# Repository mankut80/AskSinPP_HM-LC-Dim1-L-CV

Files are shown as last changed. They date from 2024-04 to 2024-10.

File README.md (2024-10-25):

# HM-LC-DIM1L-CV

## 230V Dimmeraktor (Phasenanschnitt)

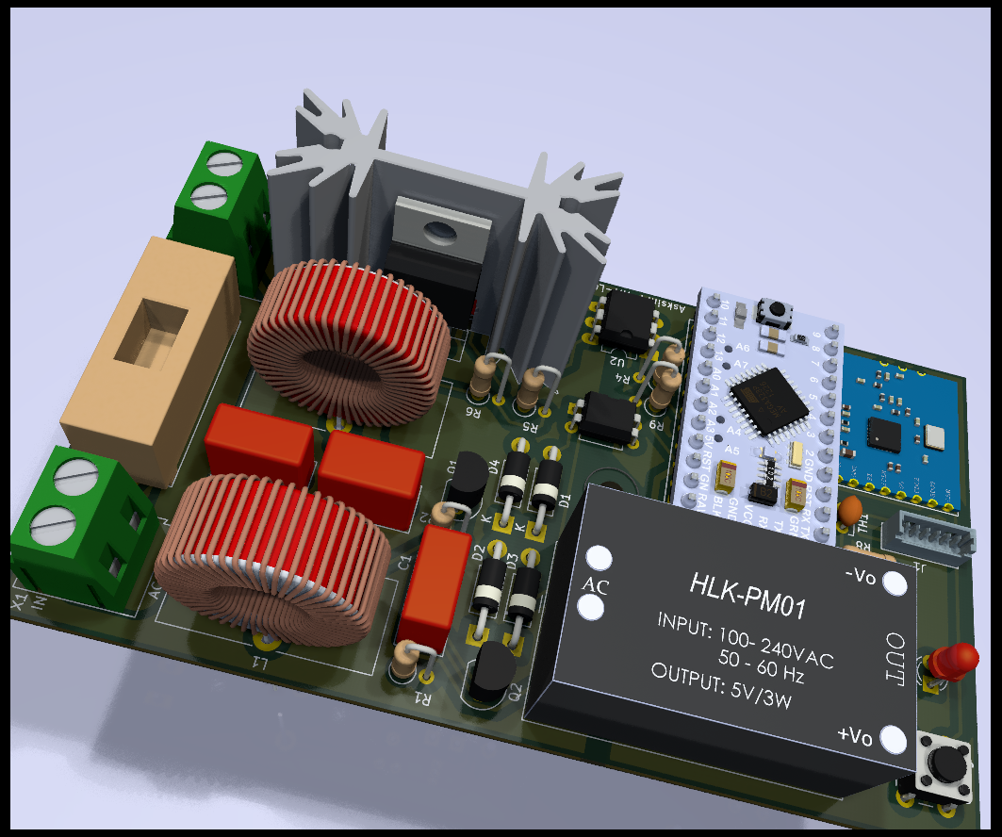
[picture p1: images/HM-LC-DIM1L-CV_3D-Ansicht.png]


*Hinweis zum Bild: das Netzteil HLK-PM01 im Bild ist in Wahrheit ein HLK-PM03 mit 3.3V Ausgangsspannung. Ich hatte leider kein passendes 3D-Modell gefunden.*

### Funktion

Mit der Technik des Phasenanschnitts lassen sich ohmsche und induktive Wechselstromlasten in der Leistung steuern. Da heutzutage wohl kaum noch jemand ein Interesse daran hat, Glühlampen zu dimmen, wird diese Schaltung eher für Motoren oder Transformatoren eingesetzt werden (Ventilatoren, Abluftmotoren). Über zwei Schraubklemmleisten wird sowohl die Netzspannung als auch der Verbraucher angeschlossen.

### Schaltungsbeschreibung

Siehe [PDF](pcb/HM-LC-DIM1L-CV_Schaltplan.pdf?fileId=26955)

Die benötigte Spannung von 3.3V wird vom PCB-Netzteil PS1 bereitgestellt und dient zur Versorgung des Arduino und des CC1101-Funkmoduls.

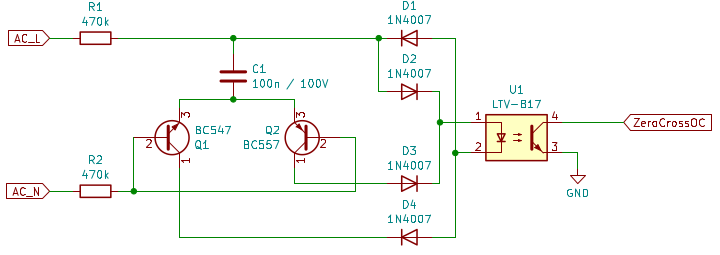
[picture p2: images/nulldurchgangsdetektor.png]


Ein diskret aufgebauter Nullspannungsdetektor liefert im Nulldurchgang der Netzspannung einen kurzen Impuls, welcher über den Optokoppler U1 an den Microcontroller gemeldet wird.

Der Leistungsteil besteht aus einem Optokoppler mit TRIAC-Ausgang welcher vom Arduino angesteuert wird, dem Leistungs-TRIAC und ein paar Filterbauteilen um Strom-/Spannungsspitzen zu dämpfen.  
Die Programmierung geschieht entweder wie üblich über den FTDI-Adapter direkt am Arduino oder über die ISP-Schnittstelle, herausgeführt an J1. J1 ist zugegeben nicht ganz die feine Art. Es ist ein in der Arduinowelt eher unüblicher Steckverbinder von Molex (Picoblade), den ich für private Zwecke gerne nutze. Er kann aber auch einfach weggelassen werden. Wer keine OTA-Updates braucht und somit nicht auf die Programmierung per ISP angewiesen ist, wird das nicht vermissen.

### Hinweise

Q1 und Q2, die beiden bipolaren Transistoren im Nulldurchgangsdetektor, können durch andere Standardtransistoren ersetzt werden. Sie müssen keine besonderen Merkmale aufweisen.  
Das Netzteil PS1 ist hoffnungslos überdimensionert, da würde auch eine Variante mit 200mA Ausgangstrom dicke ausreichen. Allerdings gab es diese Dinger nicht in einer kleineren Variante und auf ein Kondensator-"Netzteil" hatte ich keine Lust, da wäre das flashen mangels galvanischer Trennung zum Abenteuer geworden.

Der Haupt-TRIAC D6 kann auch durch andere Typen ersetzt werden. Die Wahl fiel von meiner Seite aus auf den BT138 weil mir dieser in Massen zur Verfügung steht ;-). Wer besonders kleine Leistungen schalten will, mag eventuell einen TRIAC mit kleinerem Haltestrom bevorzugen. Beim BT138 liegt dieser Haltestrom zwischen 4 und 30mA. In der Praxis bedeutet ein zu großer Haltestrom, dass die Last bei niedriger Leistungseinstellung zu flackern beginnt und eine ordentliche Steuerung erst ab höheren Steuergraden (>50%) möglich ist.

Der Heißleiter TH1 ist ebenfalls optional. Er dient zur Überwachung der Gehäuseinnentemperatur. Bei Bedarf kann man die Anschlüsse verlängern und ihn in der Nähe des Kühlkörpers platzieren. Oder ihn ganz weglassen (und im .ino-File auskommentieren).

#### Achtung 230V!

Bitte Vorsicht beim Nachbau. Wird der TRIAC ohne Isolierung am Kühlkörper angebracht, steht dieser unter Spannung, da fasst man leicht mal hin. Beim Anschluss des Verbrauchers darauf achten, dass dieser die Phase eventuell an einem bestimmten Anschluss haben will (z.B. bei einer Lampenfassung, da darf das Gewinde nicht auf die Phase gelegt werden). Rein von der Funktion her ist es egal, wo Phase und wo N angeschlossen wird.

### Bauteilliste

| Pos | Ref | Wert |
|-----|-----|---|
| 1 | C3, C4 | 47nF / 400V , RM 7.5, 10.3x7.5mm |
| 2 | C1, C2 | 100nF / 400V , RM 7.5, 10.3x7.5mm |
| 3 | R1, R2 | 470k, Bauform 0207, 1/4W |
| 4 | R3 | 330R, Bauform 0207, 1/4W |
| 5 | R4 | 150R, Bauform 0207, 1/4W |
| 6 | R5 | 360R, Baeeuform 0207, 1/4W |
| 7 | R6, R7 | 470R, Bauform 0207, 1/4W |
| 8 | R8 | 10k, Bauform 0207, 1/4W |
| 9 | R9 | 10k, Bauform 0207, 1/4W |
| 10 | L1, L2 | 100µH, 6A, Spule, z.B. Würth WUE 7447070 (bei Reichelt) |
| 11 | D1 - D4 | 1N4007 Gleichrichterdiode |
| 12 | D5 | LED, 3mm, Farbe egal |
| 13 | D6 | TRIAC BT138-600, TO220-Gehäuse |
| 14 | U1 | LTV-817 Optokoppler, DIP4 |
| 15 | U2 | MOC3052M Optokoppler mit TRIAC-Ausgang, DIP6 |
| 16 | U3 | CC1101-Funkmodul |
| 17 | X1, X2 | Schraubklemme 2pol., RM 5.08 oder RM5.00 |
| 18 | F1 | Sicherungshalter für Feinsicherungen 5x20mm und Sicherung 4A mittelträge |
| 19 | SW1 | Kurzhubtaster 6x6mm |
| 20 | A1 | Arduino Pro Mini 3.3V, 8MHz |
| 21 | PS1 | HLK-PM03 von HiLink, Netzteil 3.3V |
| 22 | Q1 | BC547, TO92, NPN-Transistor |
| 23 | Q2 | BC557, TO92, PNP-Transistor |
| 24 | TH1 | NTC 10k, Heißleiter, RM 2.5 |
| 25 | HS1 | Kühlkörper SK104 von Fischer |
| 26 | J1 | Molex Picoblade 53047-0610, Steckverbinder für ISP |

### Gehäuse

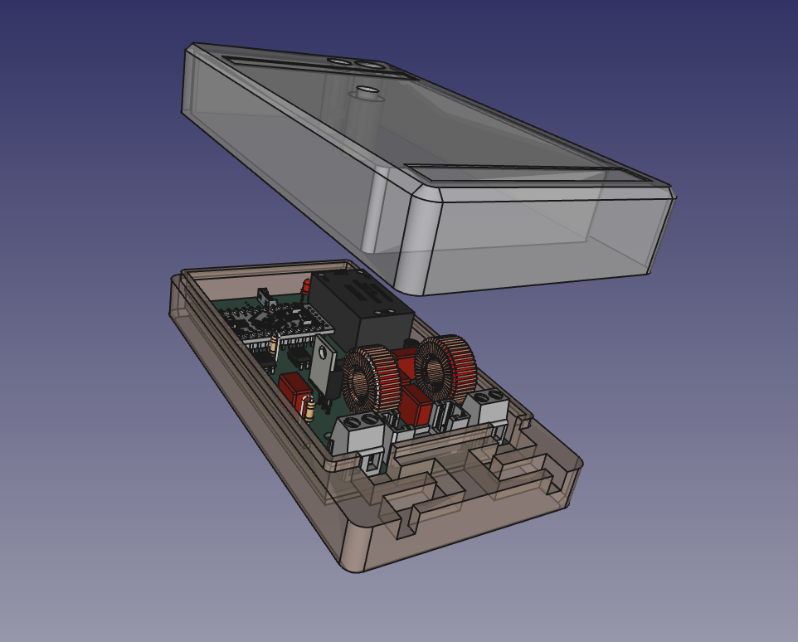
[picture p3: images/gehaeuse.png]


Das Gehäuse wurde in FreeCAD entworfen, die [Originaldatei](CAD/HM_AsksinPP_Phasenanschnitt_Gehaeuse.FCStd?fileId=26970) und zwei Step-Dateien ([Deckel](CAD/HM_AsksinPP_Phasenanschnitt_Gehaeuse-Oberteil.step?fileId=26968) und [Boden](CAD/HM_AsksinPP_Phasenanschnitt_Gehaeuse-Unterteil.step?fileId=26969)) zum Import in den Slicer (Prusaslicer frisst direkt step-Dateien) sind im CAD-Verzeichnis zu finden. Die lustigen, gezackten Vertiefungen für die Anschlussleitungen dienen als Zugentlastung. Im Deckel sind zwei kleine rechteckige Vertiefungen für Beschriftungsbänder, so man denn will.

Fertig aufgebaut sieht es dann so aus:

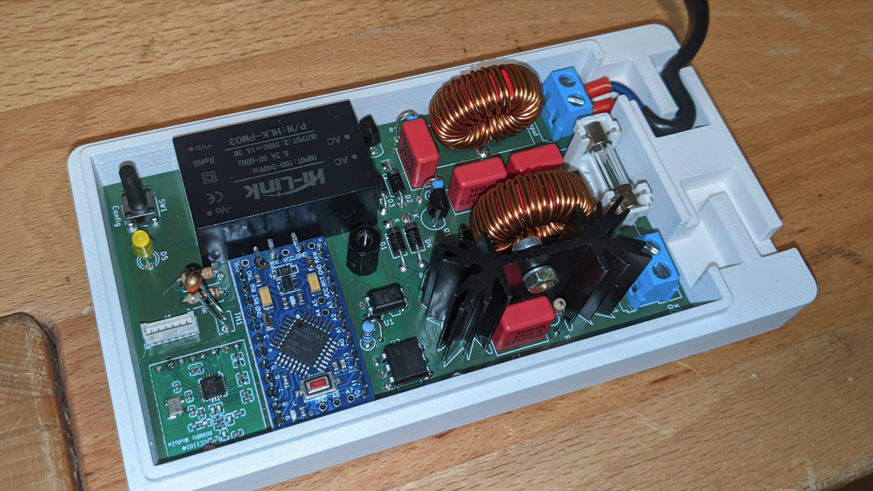
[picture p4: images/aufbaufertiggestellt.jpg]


Das Bild zeigt noch die Platine in der Revision A (aktuell ist C) mit einigen Fehlern, deshalb gleicht sie nicht 100%ig dem Bestückungsplan. Das CC1101-Modul hat als Antenne eine 83mm lange Litzenleitung bekommen, die sich im Gehäuse in einem kleinen Schlitz an der Seite verlegen lässt.

### Sketch

Als Sketch kommt eine abgeänderte Vorlage aus dem Asksin-Repo zum EInsatz. Die Serial muss natürlich geändert werden, außerdem ...

Ohne die  folgenden Änderungen wird nach dem EInschalten wiederholt (alle 40ms) kurz eingeschaltet, außerdem schaltet er nicht zuverlässig aus (geht manchmal auf Dauer-AN)

im main (\*.ino)-file, Funktion void setup():

```
phaseCut.stop();
```

innerhalb void loop():

```
if(!phaseCut.isrunning()) digitalWrite(DIMMERPIN, false);
```

Ohne die  folgenden Änderungen wird bei einer Dim-Einstellung von "0" auf Dauer-An gestellt:  
PhaseCut.cpp, Zeile 130:

```
if (_timer < 76 ) digitalWrite(OUTPUT_PIN, HIGH);
```
PhaseCut.cpp, Zeile 113, korrigieren des Setzens der Bits von Register TCCR2B (ist eher kosmetischer Natur):
```
TCCR2B |= (1 << CS20) | (1 << CS21) | (1 << CS22) ;
```

PWM.h, Zeile 25:

```
static const uint8_t zctable[50] PROGMEM = {
 9, 12, 13, 14, 15, 16, 17, 18, 19, 20, 21, 22, 23, 24, 25,26, 27, 28, 29, 30, 31, 32, 33, 34, 35, 36, 37, 38, 39, 40,41, 42, 43, 44, 45, 46, 47, 48, 49, 50, 53, 55, 60, 62, 64, 68, 70, 72, 76
};
```

PWM.h, Zeile 86:

```
#if PHASECUTMODE == 1    
  uint8_t offset = (STEPS - value)*49/STEPS;
```

Außerdem noch diese Änderung:
PhaseCut.h, Zeilen 10-16: 
Die Definitionen für PHASECUTMODE und ZEROPIN müssen abgeändert werden. Diese werden seltsamerweise nicht aus dem *.ino-File übernommen (vielen Dank an ivo-int für die Nachreichung dieser Information):

```
#ifndef PHASECUTMODE
#define PHASECUTMODE 1
#endif 

#ifndef ZEROPIN
#define ZEROPIN 3
#endif
```

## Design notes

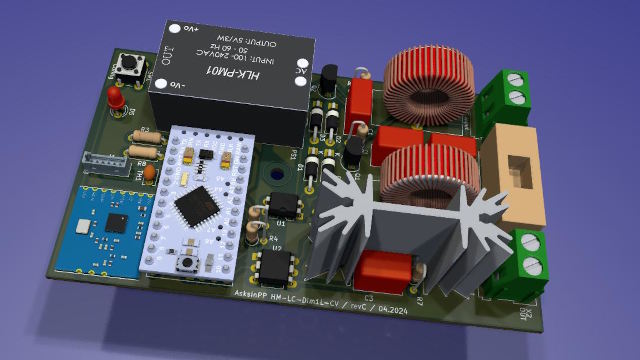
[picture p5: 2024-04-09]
images/thumb.jpg

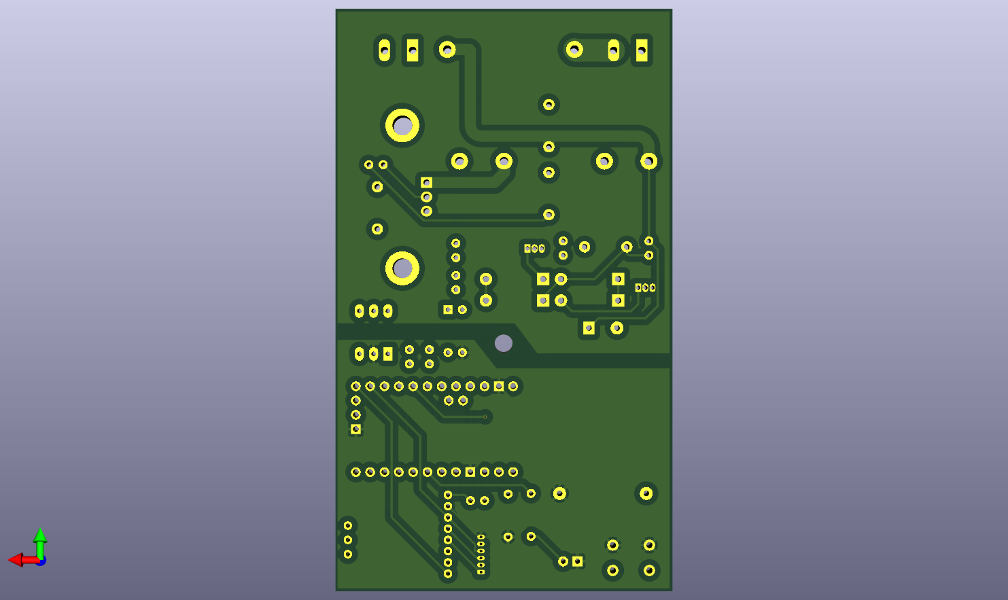
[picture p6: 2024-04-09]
pcb/HM-LC-DIM1L-CV_Board_Ansicht_unten.png

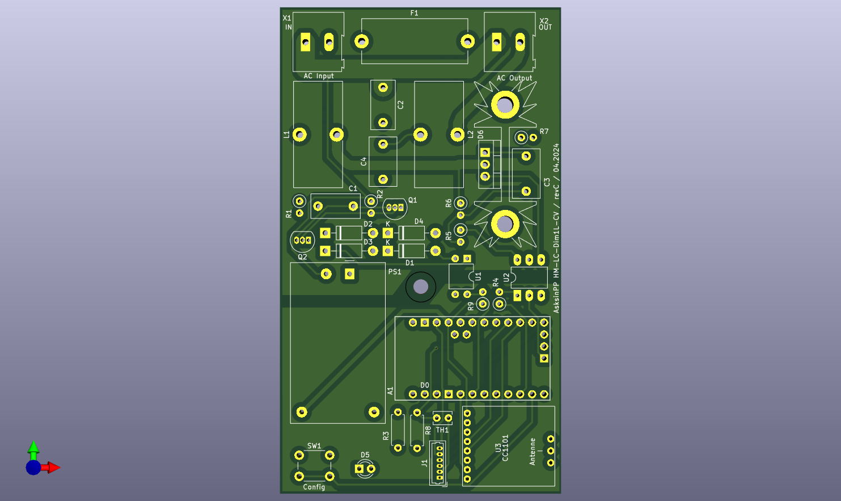
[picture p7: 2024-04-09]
pcb/HM-LC-DIM1L-CV_Board_Ansicht_oben.png

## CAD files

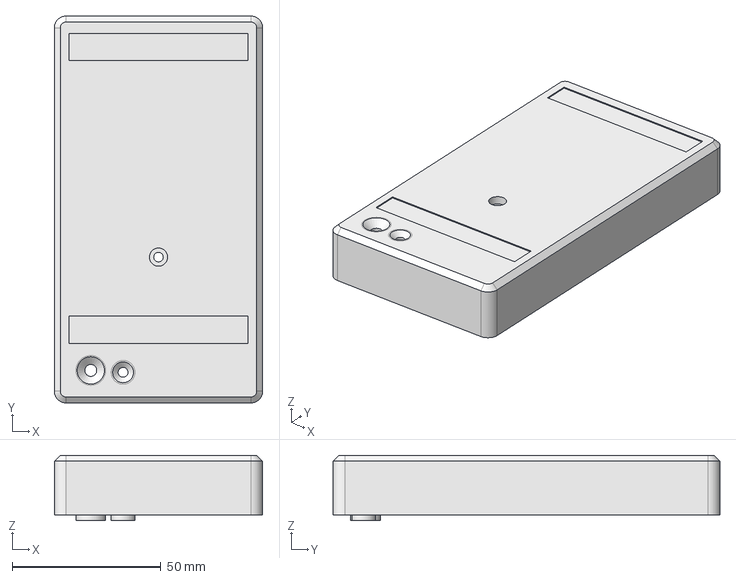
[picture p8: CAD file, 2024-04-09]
CAD/HM_AsksinPP_Phasenanschnitt_Gehaeuse-Oberteil.step
70.0 x 130.0 x 22.0 mm

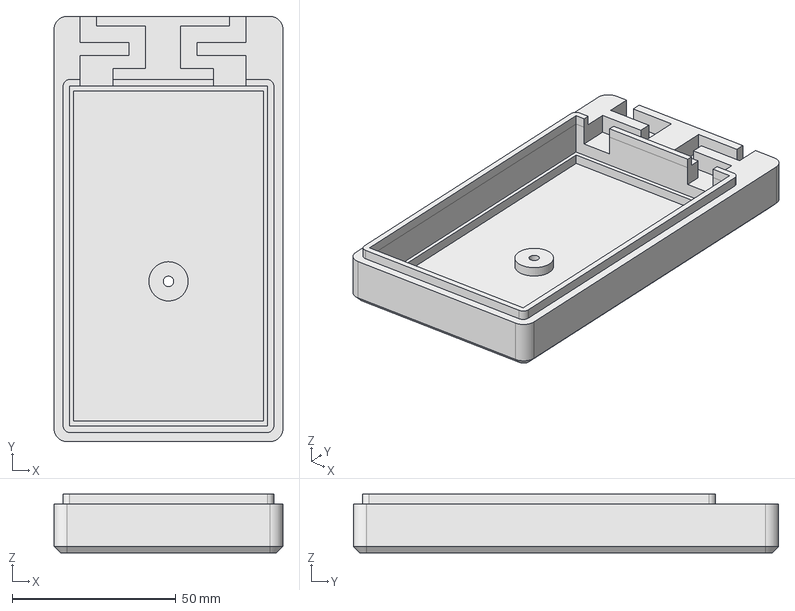
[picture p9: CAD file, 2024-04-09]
CAD/HM_AsksinPP_Phasenanschnitt_Gehaeuse-Unterteil.step
70.0 x 130.0 x 18.0 mm

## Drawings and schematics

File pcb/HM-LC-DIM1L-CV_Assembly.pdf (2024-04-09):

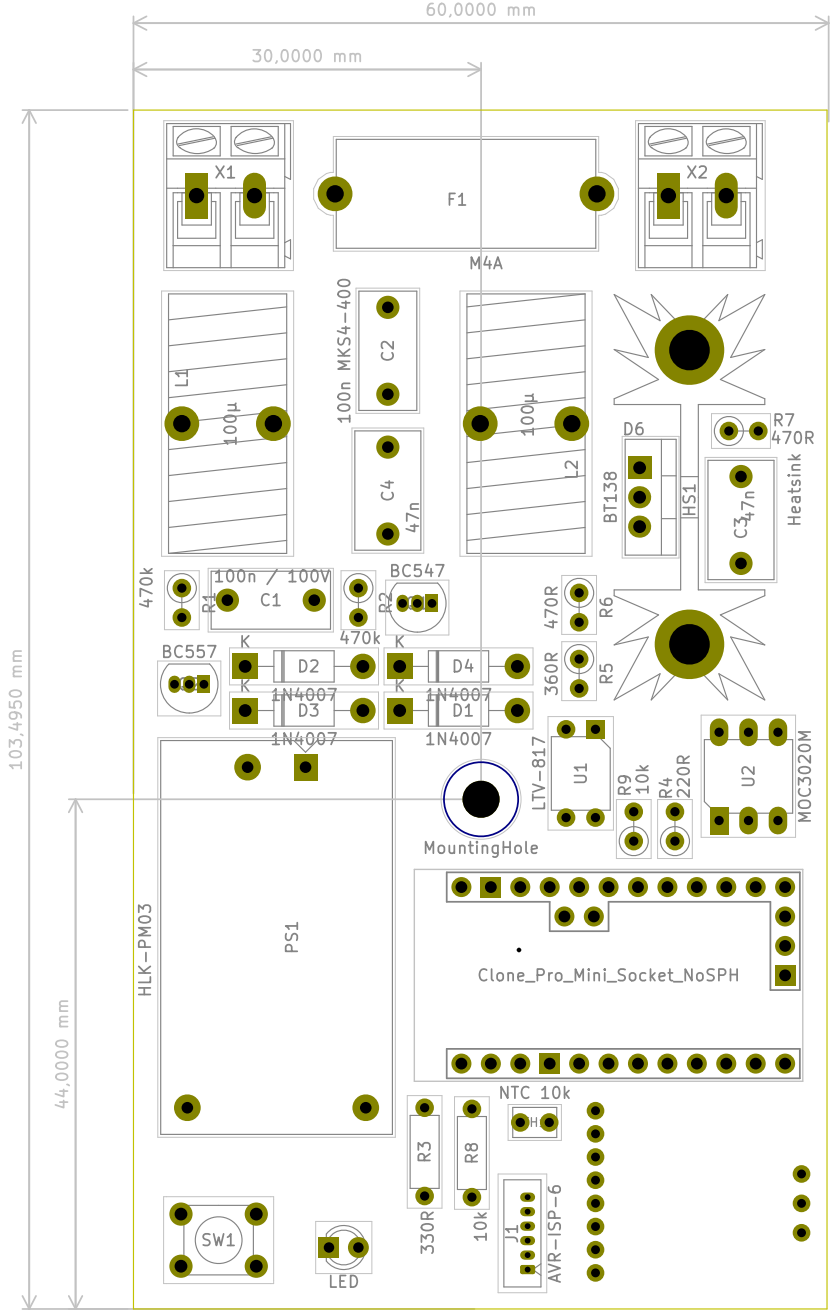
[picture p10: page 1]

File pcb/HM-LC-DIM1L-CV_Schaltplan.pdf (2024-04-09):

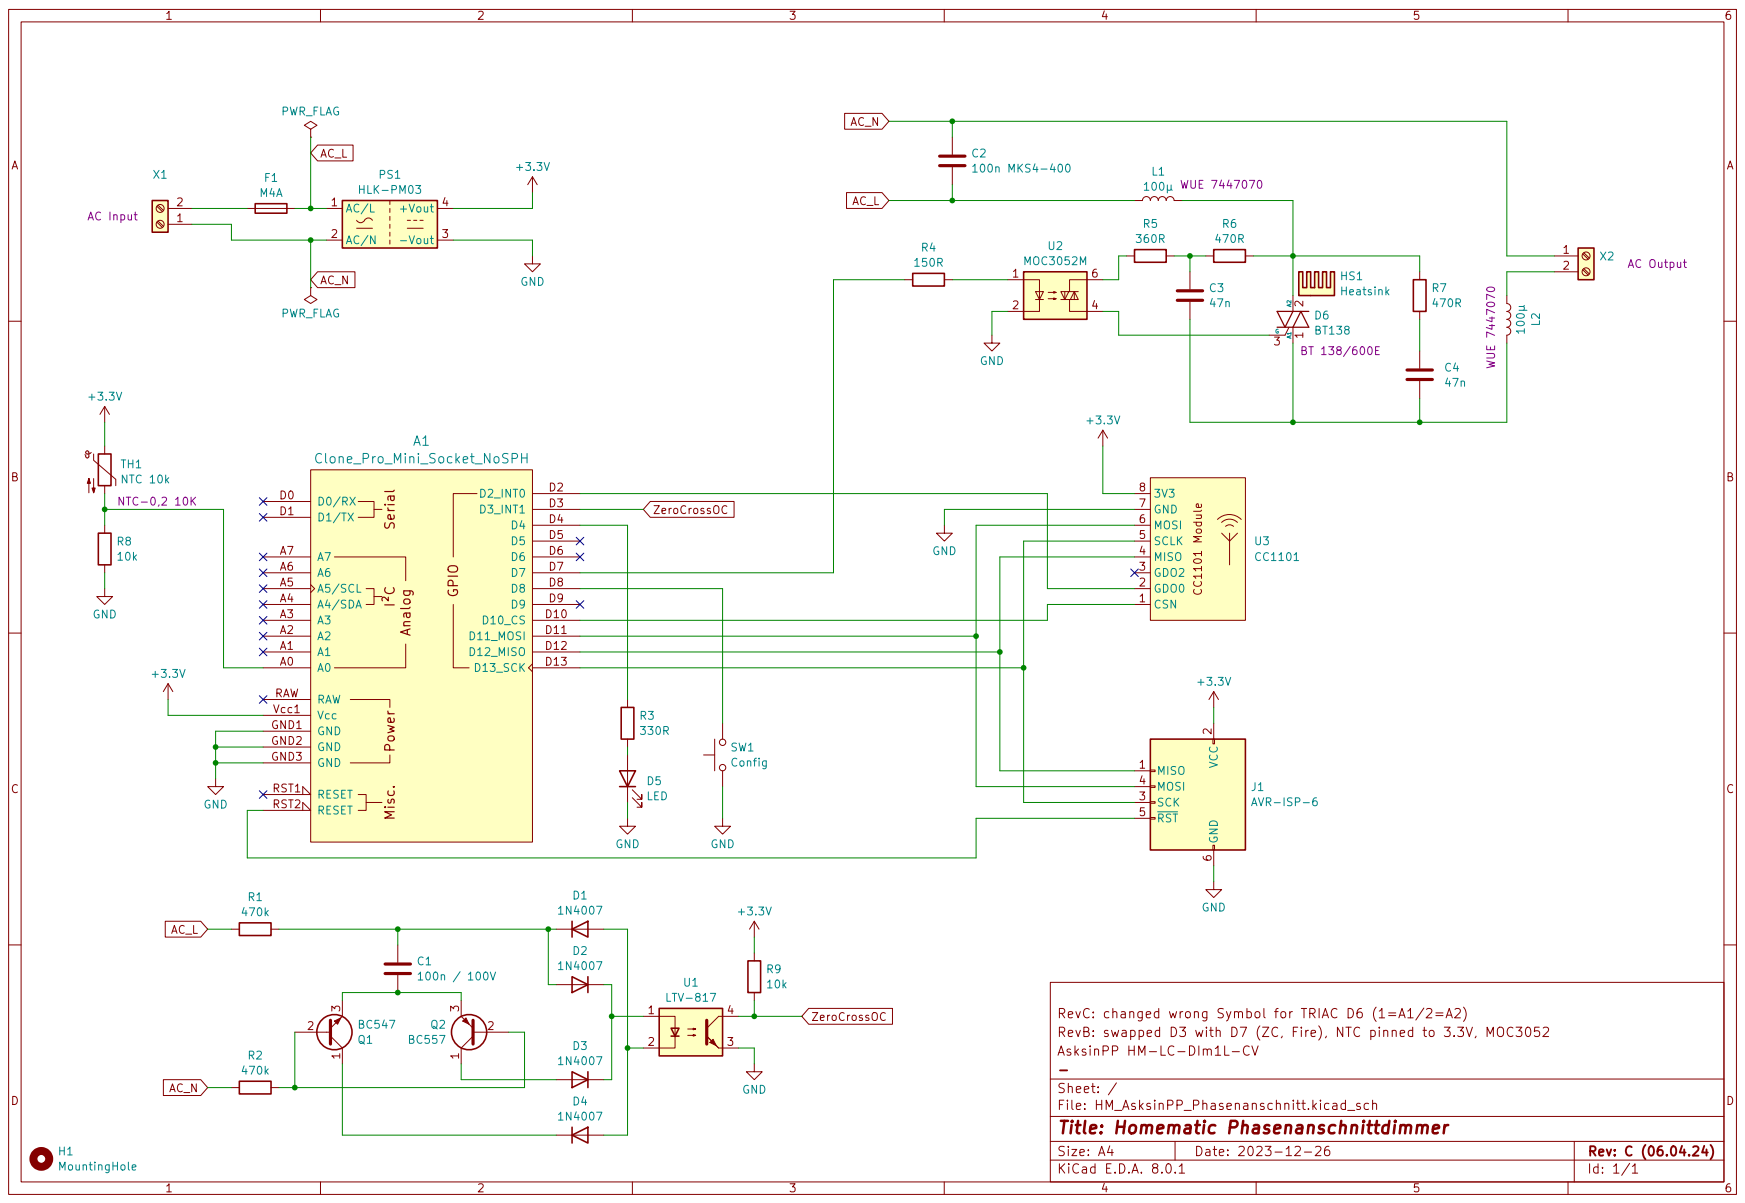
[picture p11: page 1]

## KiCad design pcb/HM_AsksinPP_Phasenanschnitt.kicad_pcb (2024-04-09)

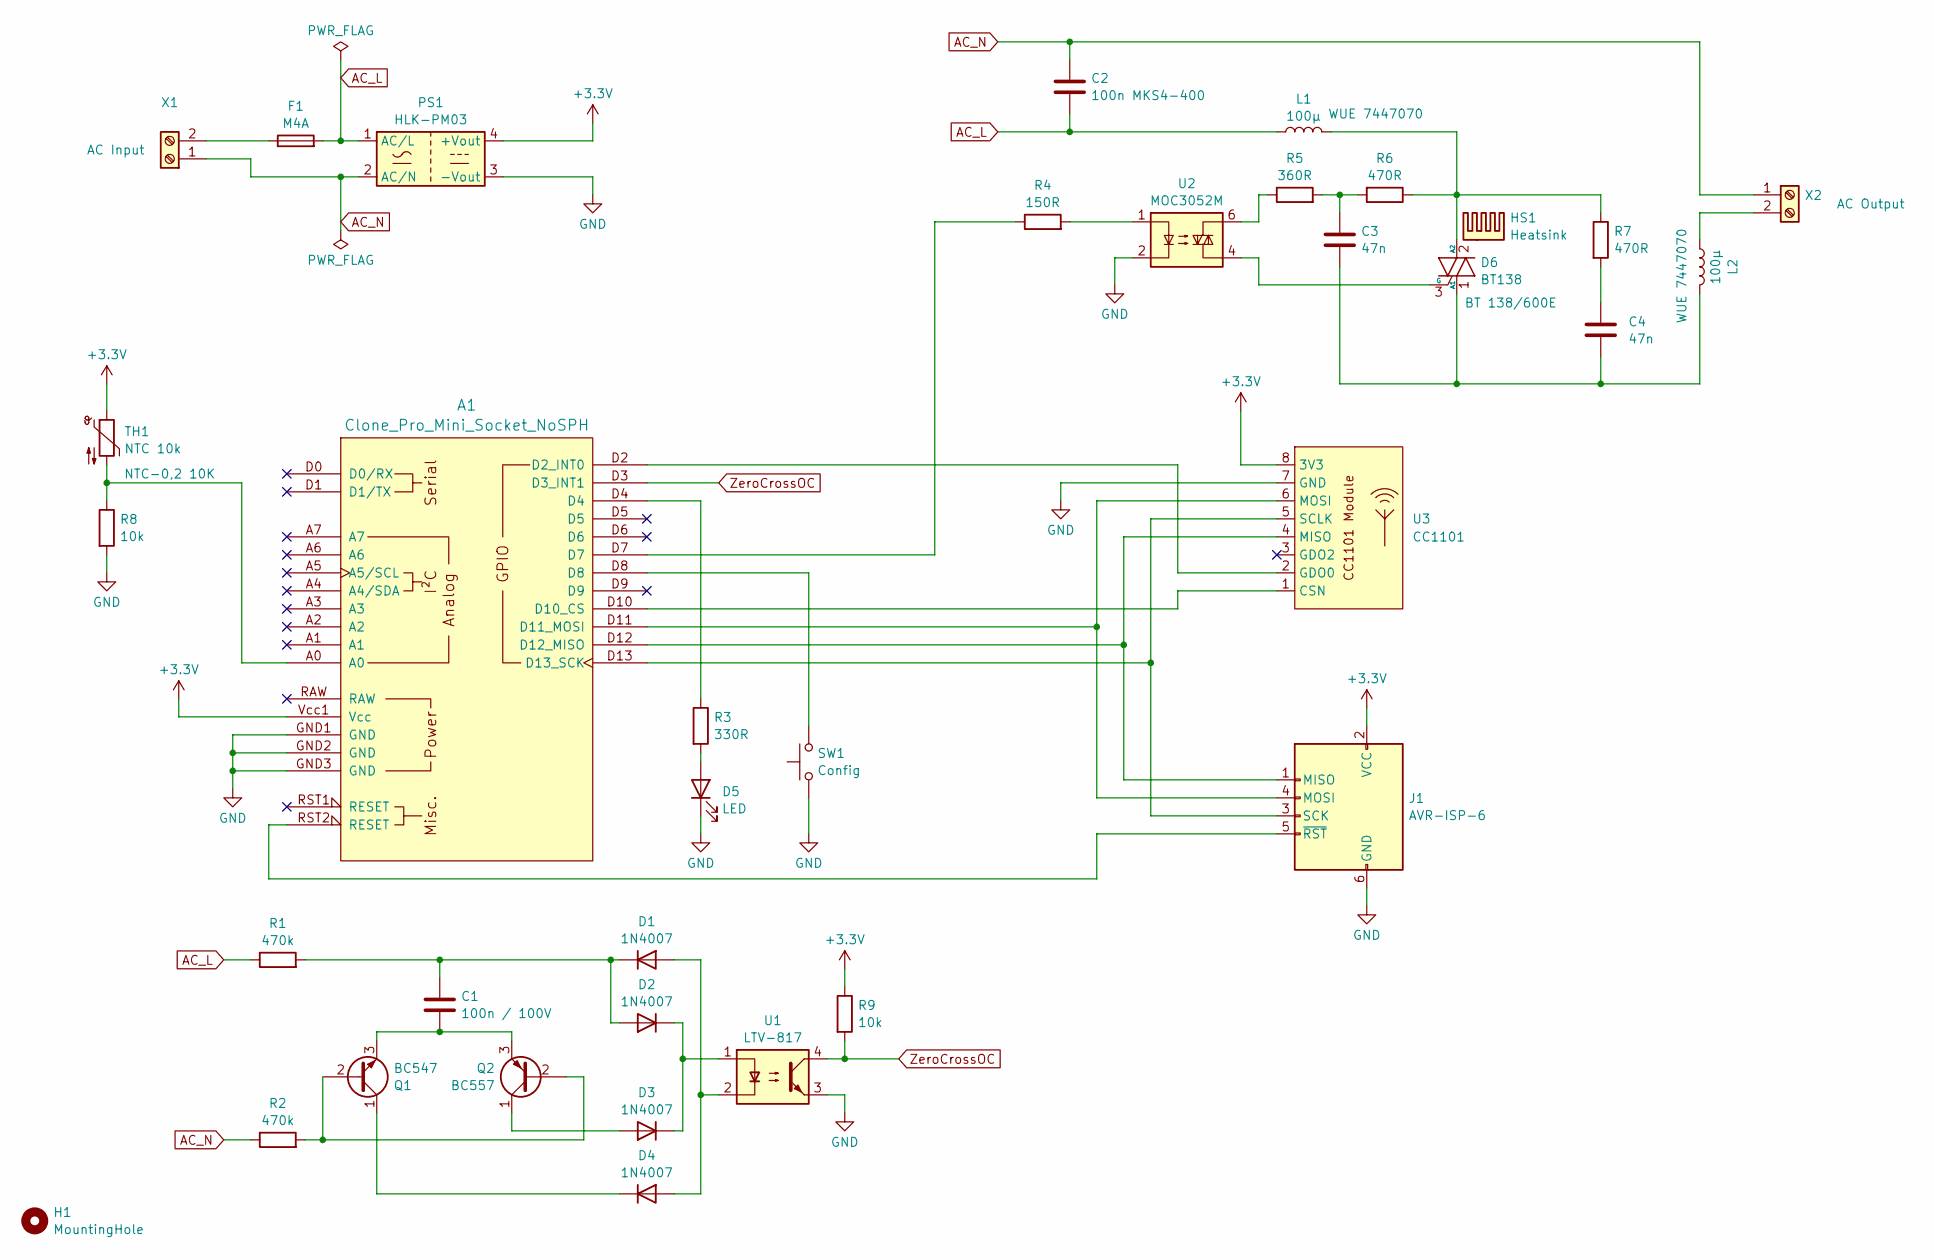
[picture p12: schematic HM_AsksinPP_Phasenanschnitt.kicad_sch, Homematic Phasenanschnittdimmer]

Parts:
A1: Clone_Pro_Mini_Socket_NoSPH
C1: 100n / 100V; C_Rect_L10.3mm_W5.0mm_P7.50mm_MKS4
C2: 100n MKS4-400; C_Rect_L10.3mm_W5.0mm_P7.50mm_MKS4
C3, C4: 47n; C_Rect_L10.3mm_W5.7mm_P7.50mm_MKS4
D1, D2, D3, D4: 1N4007; D_DO-41_SOD81_P10.16mm_Horizontal
D5: LED; LED_D3.0mm
D6: BT138; TO-220-3_Vertical
F1: M4A; Fuseholder_Cylinder-5x20mm_Stelvio-Kontek_PTF78_Horizontal_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
H1: MountingHole; MountingHole_3.2mm_M3
HS1: Heatsink; Heatsink_Fischer_SK104-STCB_35x13mm__2xDrill3.5mm_ScrewM3
J1: AVR-ISP-6; Molex_PicoBlade_53047-0610_1x06_P1.25mm_Vertical
L1, L2: 100µ; L_Toroid_Vertical_L22.4mm_W10.2mm_P7.90mm_Vishay_TJ4
PS1: HLK-PM03; Converter_ACDC_HiLink_HLK-PMxx
Q1: BC547; TO-92_Inline
Q2: BC557; TO-92_Inline
R1, R2: 470k; R_Axial_DIN0207_L6.3mm_D2.5mm_P2.54mm_Vertical
R3: 330R; R_Axial_DIN0207_L6.3mm_D2.5mm_P7.62mm_Horizontal
R4: 150R; R_Axial_DIN0207_L6.3mm_D2.5mm_P2.54mm_Vertical
R5: 360R; R_Axial_DIN0207_L6.3mm_D2.5mm_P2.54mm_Vertical
R6, R7: 470R; R_Axial_DIN0207_L6.3mm_D2.5mm_P2.54mm_Vertical
R8: 10k; R_Axial_DIN0207_L6.3mm_D2.5mm_P7.62mm_Horizontal
R9: 10k; R_Axial_DIN0207_L6.3mm_D2.5mm_P2.54mm_Vertical
SW1: Config; SW_PUSH_6mm_H5mm
TH1: NTC 10k; C_Disc_D3.8mm_W2.6mm_P2.50mm
U1: LTV-817; DIP-4_W7.62mm
U2: MOC3052M; DIP-6_W7.62mm_LongPads
U3: CC1101; CC1101_Module_v1
X1, X2: Screw_Terminal_01x02; TerminalBlock_Altech_AK300-2_P5.00mm

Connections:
+3.3V: A1.Vcc1 (Vcc), J1.2 (VCC), PS1.4 (+Vout), R9.1, TH1.1, U3.8 (3V3)
AC_L: C2.2, F1.2, L1.1, PS1.1 (AC/L), R1.1
AC_N: C2.1, PS1.2 (AC/N), R2.1, X1.1, X2.1
GND: A1.GND1 (GND), A1.GND2 (GND), A1.GND3 (GND), D5.1 (K), J1.6 (GND), PS1.3 (-Vout), R8.2, SW1.1, U1.3, U2.2, U3.7 (GND)
unnamed: A1.D2 (D2_INT0), U3.2 (GDO0)
unnamed: A1.D10 (D10_CS), U3.1 (CSN)
unnamed: A1.D11 (D11_MOSI), J1.4 (MOSI), U3.6 (MOSI)
unnamed: A1.D12 (D12_MISO), J1.1 (MISO), U3.4 (MISO)
unnamed: A1.D13 (D13_SCK), J1.3 (SCK), U3.5 (SCLK)
unnamed: A1.A0, R8.1, TH1.2
unnamed: A1.D4, R3.1
unnamed: A1.D7, R4.1
unnamed: A1.D8, SW1.2
unnamed: C3.1, R5.2, R6.2
unnamed: C4.1, R7.2
unnamed: D1.2 (A), D4.2 (A), U1.2
unnamed: C1.1, D1.1 (K), D2.2 (A), R1.2
unnamed: D2.1 (K), D3.1 (K), U1.1
unnamed: D3.2 (A), Q2.1 (C)
unnamed: D4.1 (K), Q1.1 (C)
unnamed: D5.2 (A), R3.2
unnamed: D6.2 (A2), L1.2, R6.1, R7.1
unnamed: C3.2, C4.2, D6.1 (A1), L2.2
unnamed: D6.3 (G), U2.4
unnamed: A1.RST2 (RESET), J1.5 (~RST)
unnamed: Q1.2 (B), Q2.2 (B), R2.2
unnamed: C1.2, Q1.3 (E), Q2.3 (E)
unnamed: R4.2, U2.1
unnamed: R5.1, U2.6
unnamed: F1.1, X1.2
unnamed: L2.1, X2.2
ZeroCrossOC: A1.D3 (D3_INT1), R9.2, U1.4

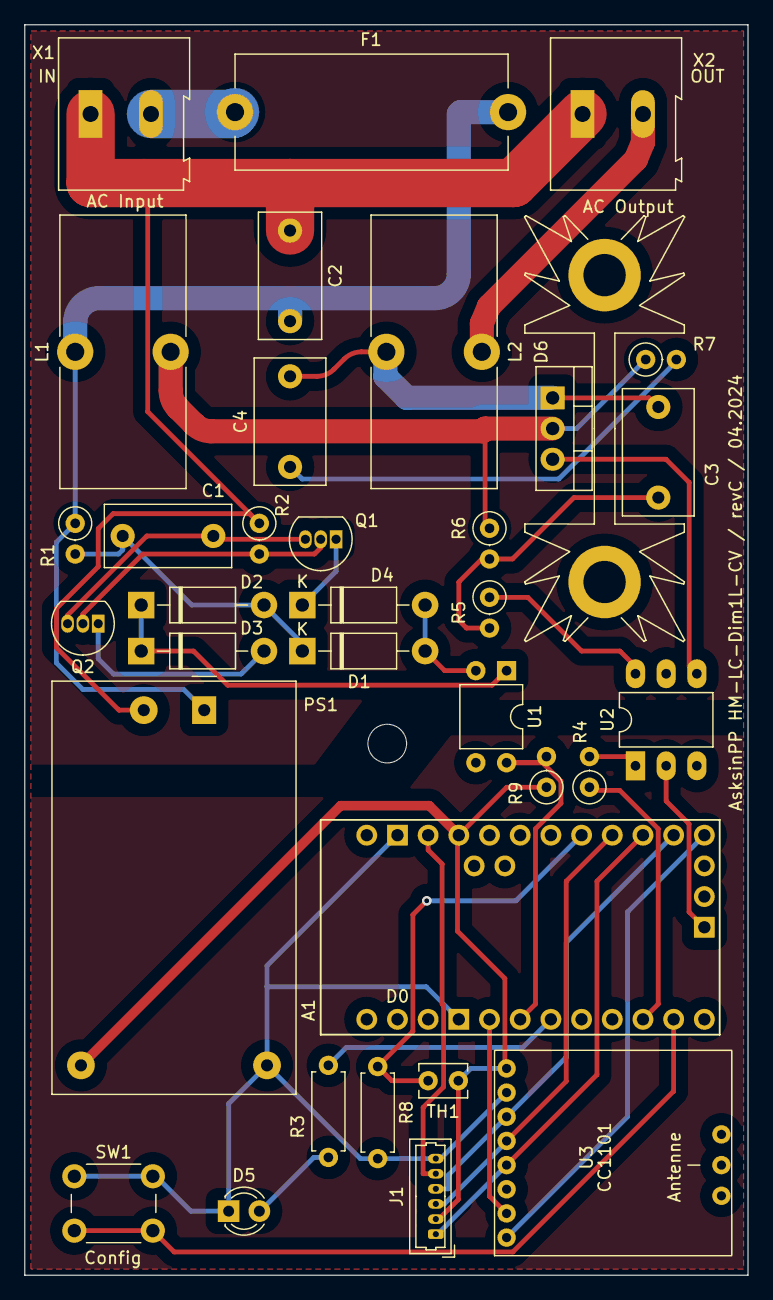
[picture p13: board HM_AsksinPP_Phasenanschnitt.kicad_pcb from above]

Board: 2 copper layers, 59.9 x 103.5 mm, 36 parts (0 on the bottom side), 32 nets.

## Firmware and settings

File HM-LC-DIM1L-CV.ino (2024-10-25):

//- -----------------------------------------------------------------------------------------------------------------------
// AskSin++
// 2016-10-31 papa Creative Commons - http://creativecommons.org/licenses/by-nc-sa/3.0/de/
// 2018-10-07 jp112sdl Creative Commons - http://creativecommons.org/licenses/by-nc-sa/3.0/de/
// 2019-01-10 scuba82 Creative Commons - http://creativecommons.org/licenses/by-nc-sa/3.0/de/
// ci-test=yes board=328p aes=no
//- -----------------------------------------------------------------------------------------------------------------------

// define this to read the device id, serial and device type from bootloader section
//#define USE_OTA_BOOTLOADER


#define NDEBUG

#define EI_NOTEXTERNAL
#define NORTC

// PIN definitions
#define DIMMERPIN          7  
#define LED_PIN            4
#define CONFIG_BUTTON_PIN  8
#define GDO0_PIN           2
#define ZEROPIN            3
#define NTC_SENSE_PIN      A0
#define NTC_ACTIVATOR_PIN   0  // pin to power ntc (or 0 if connected to vcc)

// NTC definitions
#define NTC_T0 25 // temperature where ntc has resistor value of R0
#define NTC_R0 10000 // resistance both of ntc and known resistor
#define NTC_B 3977 // b value of ntc (see datasheet)
#define NTC_OVERSAMPLING 2 // number of additional bits by oversampling (should be between 0 and 6, highly increases number of measurements)

// Phase Cut mode 
#define PHASECUT_MODE 1 // 0 = trailing-edge phase cut; 1 = leading-edge phase cut

// number of available peers per channel
#define PEERS_PER_DimChannel     4
#define PEERS_PER_RemoteChannel  8

#include <Wire.h>
#include <EnableInterrupt.h>
#include <AskSinPP.h>
#include <Dimmer.h>
#include <sensors/Ntc.h>


// all library classes are placed in the namespace 'as'
using namespace as;

// define all device properties
const struct DeviceInfo PROGMEM devinfo = {
    {0x10,0x12,0x22},       // Device ID
    "mankutHM02",           // Device Serial
    {0x00,0x12},            // Device Model
    0x10,                   // Firmware Version
    as::DeviceType::Dimmer, // Device Type
    {0x01,0x00}             // Info Bytes
};
/**
   Configure the used hardware
*/
typedef AvrSPI<10,11,12,13> SPIType;
typedef Radio<SPIType, GDO0_PIN> RadioType;
typedef StatusLed<LED_PIN> LedType;
typedef AskSin<LedType, NoBattery, RadioType> Hal;
Hal hal;
typedef DimmerChannel<Hal, PEERS_PER_DimChannel> DimChannel;
typedef DimmerDevice<Hal, DimChannel, 3, 3> DimDevice;

DimDevice sdev(devinfo, 0x20);
DimmerControl<Hal,DimDevice,ZC_Control<>> control(sdev);
ConfigToggleButton<DimDevice> cfgBtn(sdev);

class TempSens : public Alarm {
  Ntc<NTC_SENSE_PIN,NTC_R0,NTC_B,NTC_ACTIVATOR_PIN,NTC_T0,NTC_OVERSAMPLING> ntc;
  
  public:
  TempSens () : Alarm(0) {}
  virtual ~TempSens () {}

  void init () {
    ntc.init();
    set(seconds2ticks(15));
    sysclock.add(*this);
  }

  virtual void trigger (AlarmClock& clock) {
    ntc.measure();
    DPRINT("Temp: ");DDECLN(ntc.temperature());
    control.setTemperature(ntc.temperature());
    set(seconds2ticks(2));
    clock.add(*this);
  }
};
TempSens tempsensor;


void setup () {
  DINIT(57600, ASKSIN_PLUS_PLUS_IDENTIFIER);
  if( control.init(hal,DIMMERPIN) ){
    sdev.channel(1).peer(cfgBtn.peer());
  }
 
  buttonISR(cfgBtn, CONFIG_BUTTON_PIN);
  tempsensor.init();
  sdev.initDone();
  phaseCut.Stop();
  
}


void loop() {
  hal.runready();
  sdev.pollRadio();

  if(!phaseCut.isrunning()) digitalWrite(DIMMERPIN, false);
}

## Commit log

2024-10-25 Update HM-LC-DIM1L-CV.ino
    deleted '#include <Arduino>', which is only neccessary for platformIO-Users
2024-10-25 Update README.md
    Hinweis zur notwendigen Änderung der PhaseCut.h hinzugefügt
